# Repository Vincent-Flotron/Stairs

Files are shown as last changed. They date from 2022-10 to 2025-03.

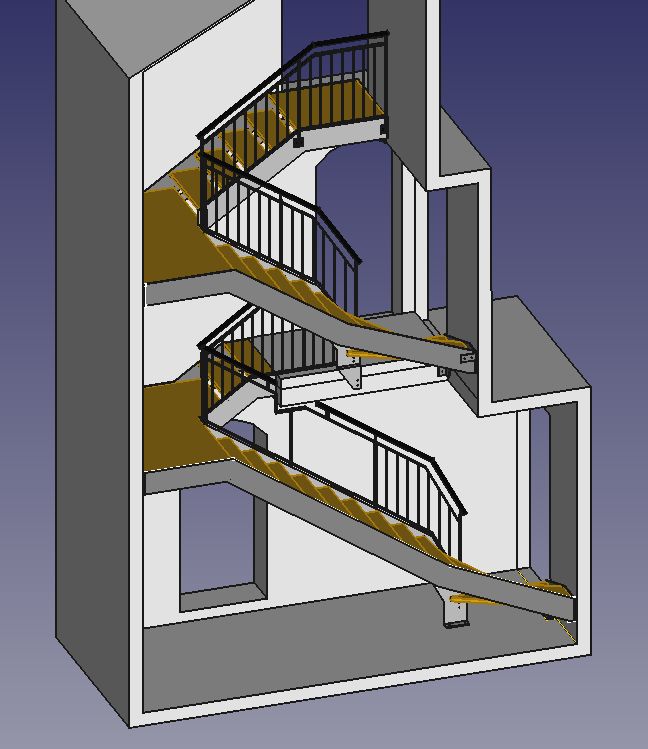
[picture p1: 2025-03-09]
overview.jpg

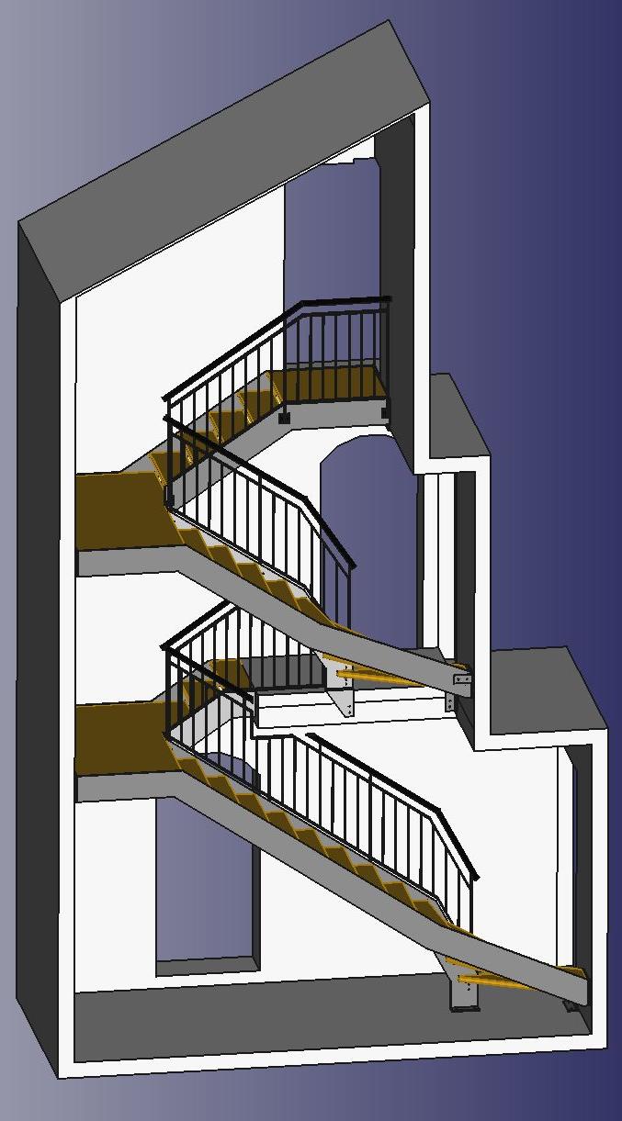
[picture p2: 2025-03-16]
VueGenerale.jpg

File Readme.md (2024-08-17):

# Escaliers fait avec FreeCAD

Voici des escaliers fait avec FreeCAD.
Ceux-ci utilisent une Spreadsheet afin de rendre certaines côtes paramétriques.

Un peu de code python a été ajouté dans le dossier Macro. Il sert à créer des body, les placer (selon la Spreadsheet) et les renommer afin de créer des marches.
Ce code est utilisé en copiant-collant son contenu dans la console FreeCAD.

Le feuille de calcul "Escalier.ods" est utilisée pour dimensionner les escaliers.

Lien sur la signification des icônes: <br/>
[https://wiki.freecad.org/Tree_view#Overlay_icons](https://wiki.freecad.org/Tree_view#Overlay_icons)

## Remerciements

Merci à [jp willm](https://www.youtube.com/channel/UCJwHW5GwrK1fq16cxUoBOUw/featured) pour ces vidéo sur FreeCAD qui m'ont beaucoup inspirées et mis à l'aise avec FreeCAD.

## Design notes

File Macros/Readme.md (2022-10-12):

# Macro

Le fichier **CreateSteps.py** n'est pas encore utilisé comme macro. Pour l'instant son contenu est copié dans la console **Freecad**. Puis la fonction **createSteps** est appelée comme ci-dessous afin de créer les corps (body) des marche et de les placer en "Z" en fonction de la Spreadsheet.

```python
createSteps(firstStep=1, nbSteps=2, firstBody=17, projectName='Maison', spreadsheet='Spreadsheet', stepPrefix='N')
```

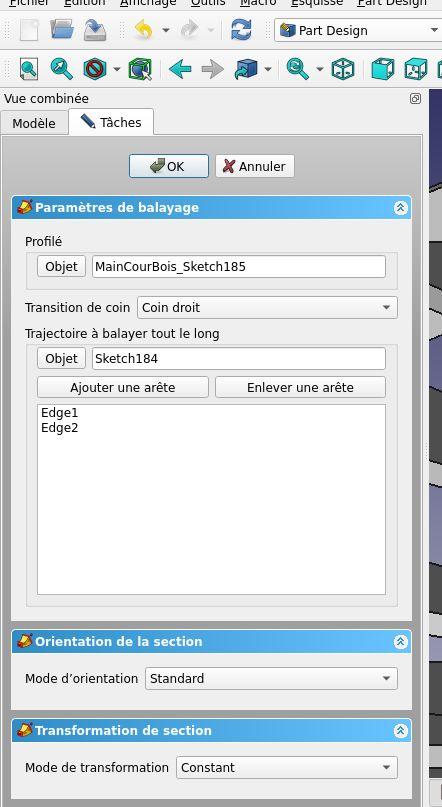
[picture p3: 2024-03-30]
mainCourante.jpg

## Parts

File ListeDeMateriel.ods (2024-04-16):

Liste de matériel :
Description | Matériau et dimensions [mm] | Quantité en barres de [6m] | Limons | fix marches | fix lim | fix barriere | barreaux
Barrières | Acier plat 10x40 | 15 | 1 | 8.4 | 0.5 | 0.195 | 22.0916666666667
Fix marches | Acier plat 8x50 | 12 | 6 | 3 |  |  | 44.1833333333333
Limons | Acier plat 15x250 | 8 | 2
Fix. Limonx | Acier plat 80x12 | 1 | 3
Fix. Barrières | Acier plat 90x10 | 1 | 2
Fix. Main courante | Acier plat 14x4 (si pas 14x4 alors 15x4) | 1 | 6
Barreaux | Acier rond Diam10 | 15
Description | Matériau et dimensions [mm] | Quantité [pce]
Vis Fix. Limons | Vis acier zingué 6 pans extérieur M16x50 | 35 | 2
 | Ecrous acier zingué 6 pans M16 | 35 | 6
 | Rondelles acier zingué ressort M16 | 35 | 2
 | Rondelles acier zingué plates M16 | 70 | 4
Vis fix barrières | Vis acier zingué 6 pans extérieur M10x35 | 25 | 2
 | Rondelles acier zingué ressort M10 | 25 | 4
 | Rondelles acier zingué plates M10 | 25 | 5
 |  | Date : 16.04.2024
 |  |  | 45 |  |  |  | 66.275

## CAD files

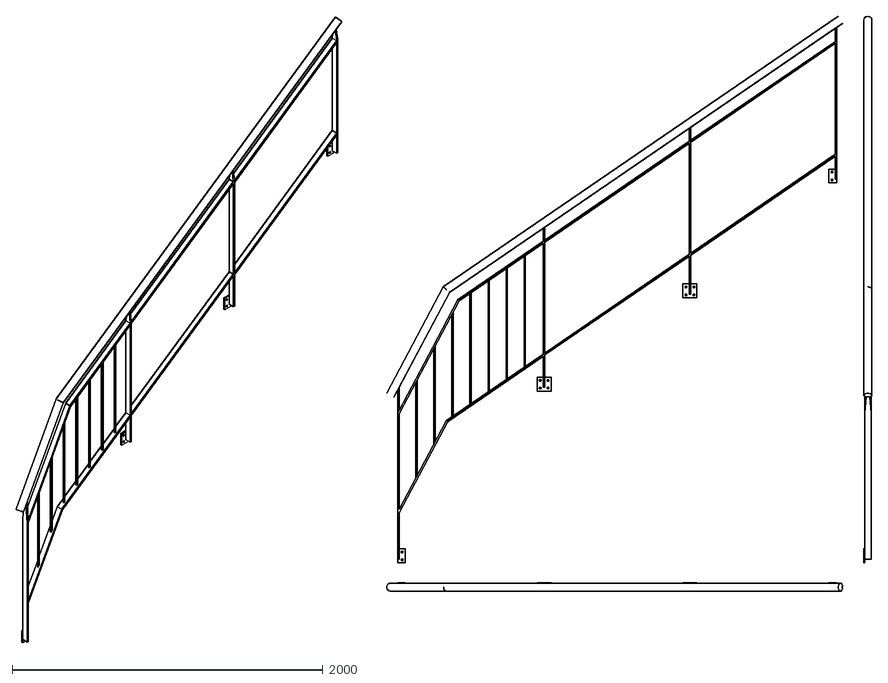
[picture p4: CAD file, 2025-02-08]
dxf/BarriereRez1ereVoleeBasGauche.dxf
5506.1 x 4028.6

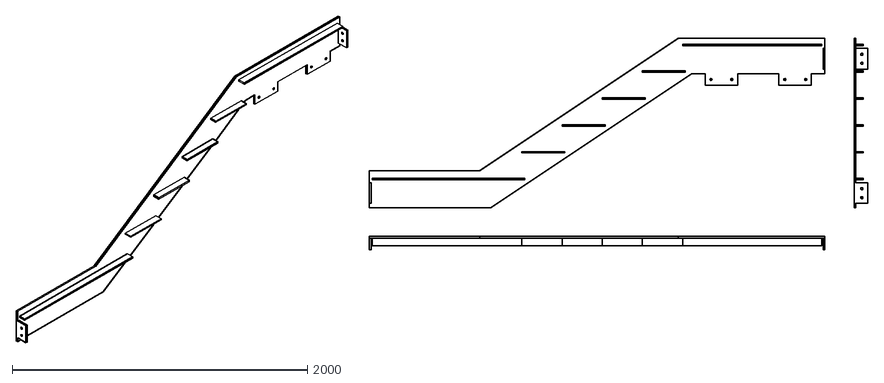
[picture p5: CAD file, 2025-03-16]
dxf/Epaiss12mm/Limon1er2emeVoleeGauche_V2.dxf
5764.3 x 2210.1

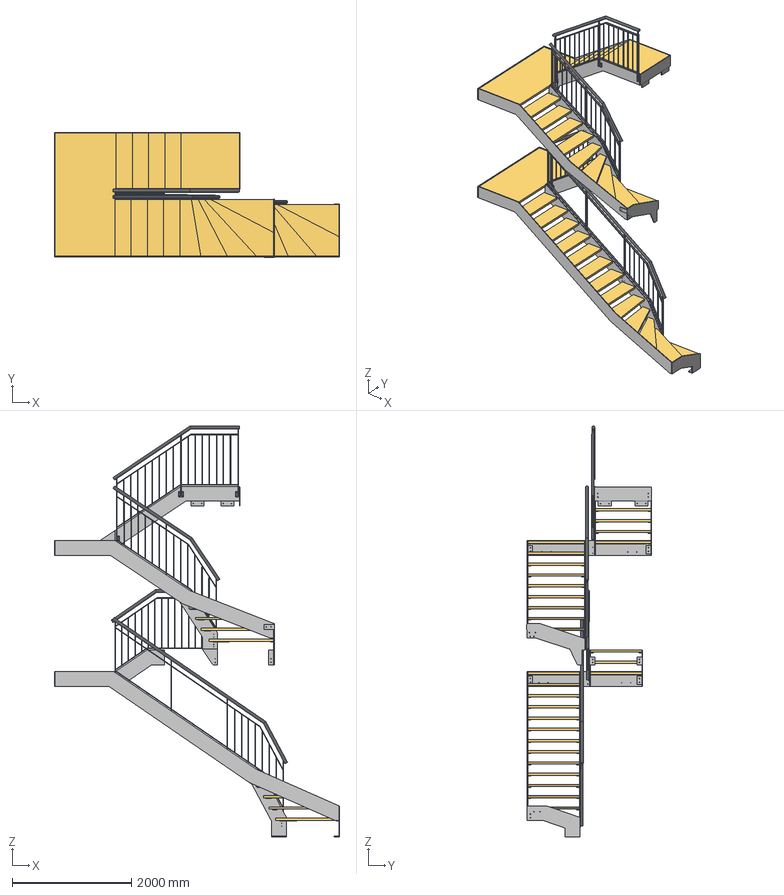
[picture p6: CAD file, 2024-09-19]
Maison2.FCStd
4779.0 x 2098.0 x 6882.0 mm
M1_Body003
M2_Body004
M3_Body005
M4_Body006
M5_Body007
M6_Body008
M7_Body009
M8_Body010
M9_Body011
M10_Body012
M11_Body013
M12_Body014
M13_Body015
M14_Body016
N1_Body017
N2_Body018
LimonRez1ereVoleeBasGauche_Body019
LimonRez1ereVoleeGauche_Body020
LimonRez2emeVoleeGauche_Body023
LimonRezPalier_Body024
NN1_Body025
NN2_Body026
NN3_Body027
NN4_Body028
NN5_Body029
NN6_Body030
NN7_Body031
NN8_Body032
NN9_Body033
NN10_Body034
NN11_Body035
NN12_Body036
NN13_Body037
NN14_Body038
NN15_Body039
Limon1er1ereVoleeBasGauche_Body040
Limon1er1ereVoleeGauche_Body041
Limon1er2emeVoleeGauche_Body043
Limon1erPalier_Body045
Limon1er2emePalier_Body046
BarriereRez1ereVoleeBasGauche_Corps
BarriereRez2emeVolee_Corps
Barriere1er1ereVolee_Corps
Barriere1er2emeVolee_Corps
LimonRez1ereVoleeDroite_Body021_Cut
LimonRez2emeVoleeDroite_Body022_Cut001
Limon1er1ereVoleeDroite_Body042_Cut003
Limon1er2emeVoleeDroite_Body044_Cut004

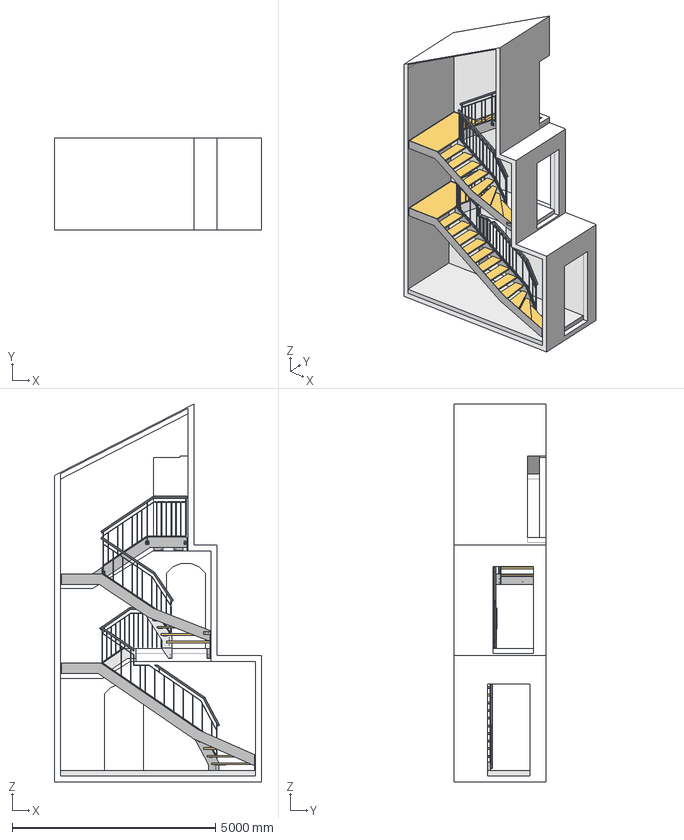
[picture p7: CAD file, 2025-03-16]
step_V2/Escaliers_V2.step
5103.0 x 2270.0 x 9300.2 mm
Murs_Body
M1_Body003
M2_Body004
M3_Body005
M4_Body006
M5_Body007
M6_Body008
M7_Body009
M8_Body010
M9_Body011
M10_Body012
M11_Body013
M12_Body014
M13_Body015
M14_Body016
N1_Body017
N2_Body018
LimonRez1ereVoleeBasGauche_Body019
LimonRez1ereVoleeGauche_Body020
LimonRez2emeVoleeGauche_Body023
LimonRezPalier_Body024
NN1_Body025
NN2_Body026
NN3_Body027
NN4_Body028
NN5_Body029
NN6_Body030
NN7_Body031
NN8_Body032
NN9_Body033
NN10_Body034
NN11_Body035
NN12_Body036
NN13_Body037
NN14_Body038
NN15_Body039
Limon1er1ereVoleeBasGauche_Body040
Limon1er1ereVoleeGauche_Body041
Limon1er2emeVoleeGauche_Body043
Limon1erPalier_Body045
Limon1er2emePalier_Body046
Chape_rez_Body
BarriereRez2emeVolee_Corps
Barriere1er1ereVolee_Corps
Barriere1er2emeVolee_Corps
LimonRez1ereVoleeDroite_Body021_Cut
LimonRez2emeVoleeDroite_Body022_Cut001
Limon1er1ereVoleeDroite_Body042_Cut003
Limon1er2emeVoleeDroite_Body044_Cut004

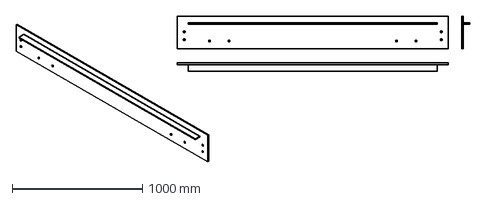
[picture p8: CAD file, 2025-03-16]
dxf/Epaiss12mm/Limon1erPalier_V2.dxf
3486.8 x 1118.4 mm

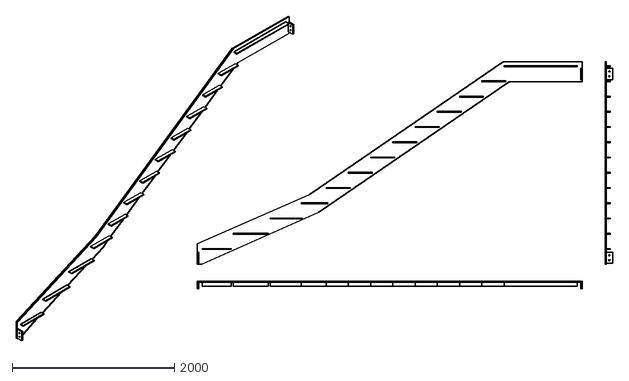
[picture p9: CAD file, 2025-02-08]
dxf/LimonRez1ereVoleeGauche.dxf
7362.8 x 4010.3

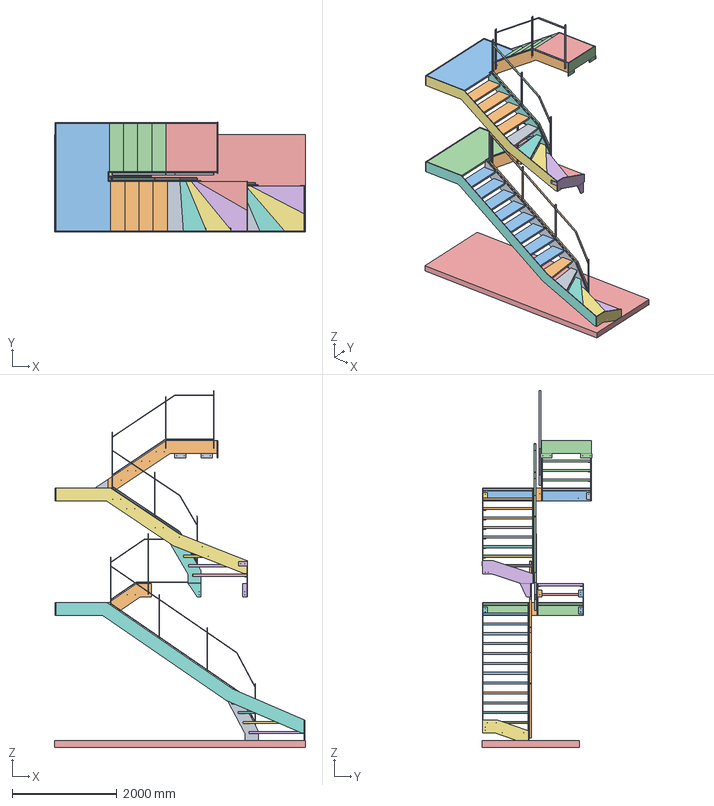
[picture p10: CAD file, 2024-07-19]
Maison2_v1.step
4803.0 x 2113.0 x 6830.0 mm
Barriere1er2emeVolee_Corps
BarriereRez1ereVoleeBasGauche_Corps
BarriereRez2emeVolee_Corps
Barriere1er1ereVolee_Corps
Chape_rez_Body
M1_Body003
M2_Body004
M3_Body005
M4_Body006
M5_Body007
M6_Body008
M7_Body009
M8_Body010
M9_Body011
M10_Body012
M11_Body013
M12_Body014
M13_Body015
M14_Body016
N1_Body017
N2_Body018
LimonRez1ereVoleeBasGauche_Body019
LimonRez1ereVoleeGauche_Body020
LimonRez1ereVoleeDroite_Body021
LimonRez2emeVoleeDroite_Body022
LimonRez2emeVoleeGauche_Body023
LimonRezPalier_Body024
NN1_Body025
NN2_Body026
NN3_Body027
NN4_Body028
NN5_Body029
NN6_Body030
NN7_Body031
NN8_Body032
NN9_Body033
NN10_Body034
NN11_Body035
NN12_Body036
NN13_Body037
NN14_Body038
NN15_Body039
Limon1er1ereVoleeBasGauche_Body040
Limon1er1ereVoleeGauche_Body041
Limon1er1ereVoleeDroite_Body042
Limon1er2emeVoleeGauche_Body043
Limon1er2emeVoleeDroite_Body044
Limon1erPalier_Body045
Limon1er2emePalier_Body046

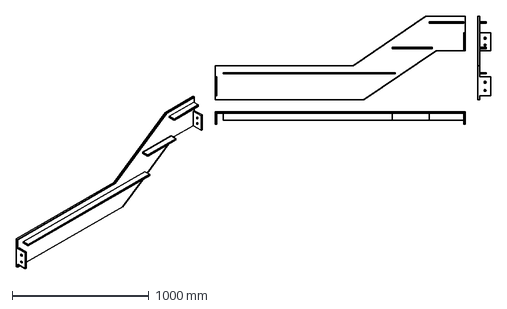
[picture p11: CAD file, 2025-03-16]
dxf/Epaiss12mm/LimonRez2emeVoleeGauche_V2.dxf
3470.2 x 1845.8 mm

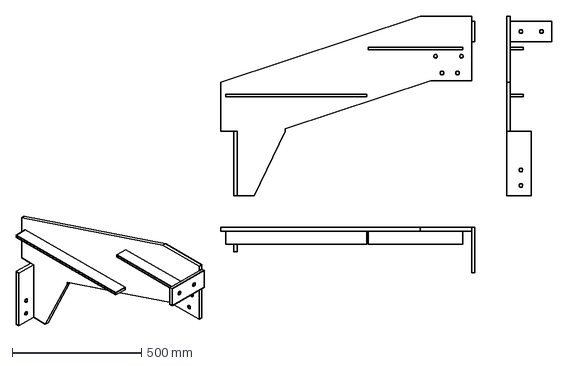
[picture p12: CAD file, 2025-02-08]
dxf/Limon1er1ereVoleeBasGauche.dxf
2071.2 x 1197.6 mm

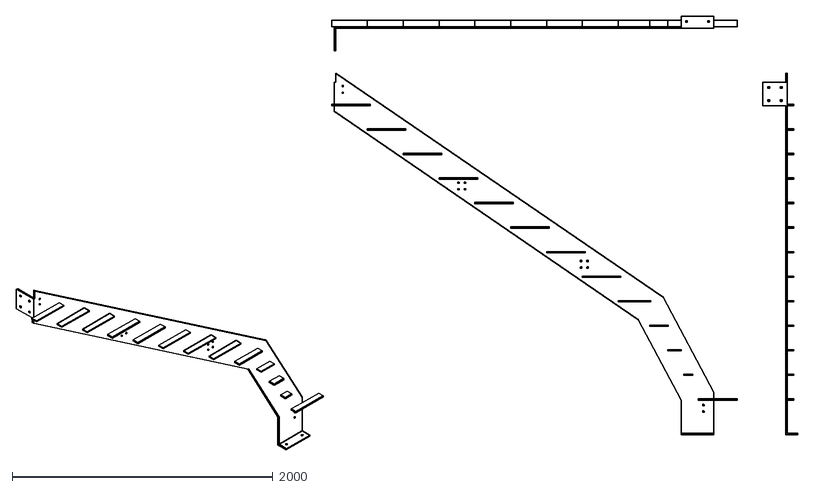
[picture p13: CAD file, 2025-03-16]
dxf/Epaiss12mm/LimonRez1ereVoleeDroite_V2.dxf
5987.0 x 3323.0

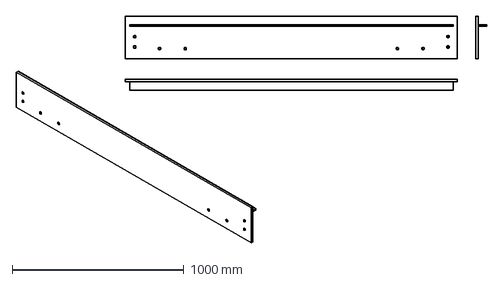
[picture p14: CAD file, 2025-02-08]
dxf/LimonRezPalier.dxf
2742.7 x 1322.5 mm

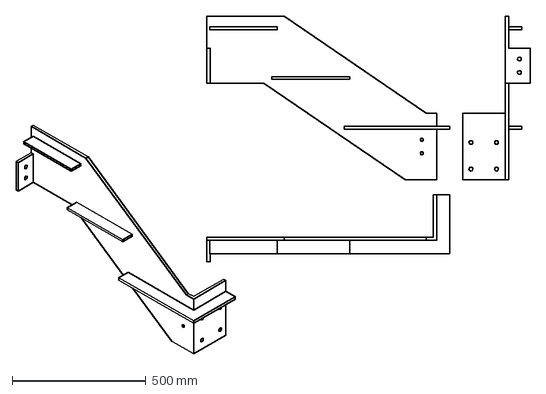
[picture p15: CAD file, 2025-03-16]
dxf/Epaiss12mm/LimonRez2emeVoleeDroite_V2.dxf
1920.2 x 1260.9 mm

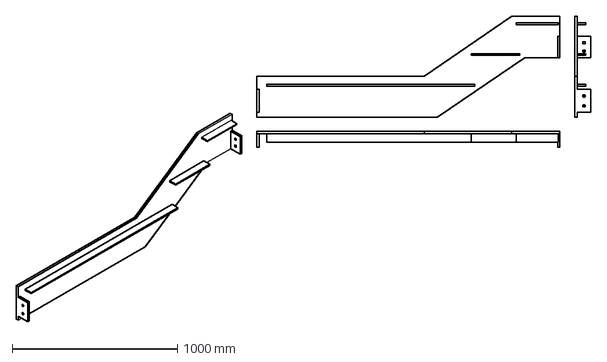
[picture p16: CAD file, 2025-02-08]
dxf/LimonRez2emeVoleeGauche.dxf
3472.8 x 1846.5 mm

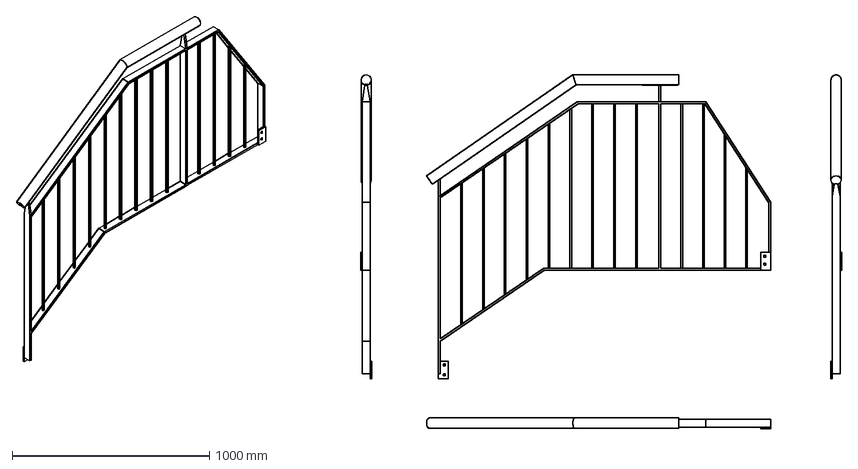
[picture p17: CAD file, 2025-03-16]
dxf/Epaiss12mm/BarriereRez2emeVolee_V2.dxf
4186.1 x 2091.0 mm

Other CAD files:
Maison.FCStd
dxf/Limon1er2emePalier.dxf
dxf/Epaiss12mm/LimonRez1ereVoleeBasGauche_V2.dxf
dxf/LimonRez2emeVoleeDroite.dxf
dxf/Barriere1er1ereVolee.dxf
dxf/Barriere1er2emeVolee.dxf
dxf/BarriereRez2emeVolee.dxf
dxf/Epaiss12mm/Barriere1er1ereVolee_V2.dxf
dxf/Epaiss12mm/Barriere1er2emeVolee_V2.dxf
dxf/Epaiss12mm/BarriereRez1ereVoleeBasGauche_V2.dxf
dxf/Epaiss12mm/Limon1er1ereVoleeBasGauche_V2.dxf
dxf/Epaiss12mm/Limon1er1ereVoleeDroite_V2.dxf
dxf/Epaiss12mm/Limon1er1ereVoleeGauche_V2.dxf
dxf/Epaiss12mm/Limon1er2emePalier_V2.dxf
dxf/Epaiss12mm/Limon1er2emeVoleeDroite_V2.dxf
dxf/Epaiss12mm/LimonRez1ereVoleeGauche_V2.dxf
dxf/Epaiss12mm/LimonRezPalier_V2.dxf
dxf/Epaiss12mm/Vue_Générale.dxf
dxf/Limon1er1ereVoleeDroite.dxf
dxf/Limon1er1ereVoleeGauche.dxf
dxf/Limon1er2emeVoleeGauche.dxf
dxf/Limon1erPalier.dxf
dxf/LimonRez1ereVoleeBasGauche.dxf
dxf/LimonRez1ereVoleeDroite.dxf

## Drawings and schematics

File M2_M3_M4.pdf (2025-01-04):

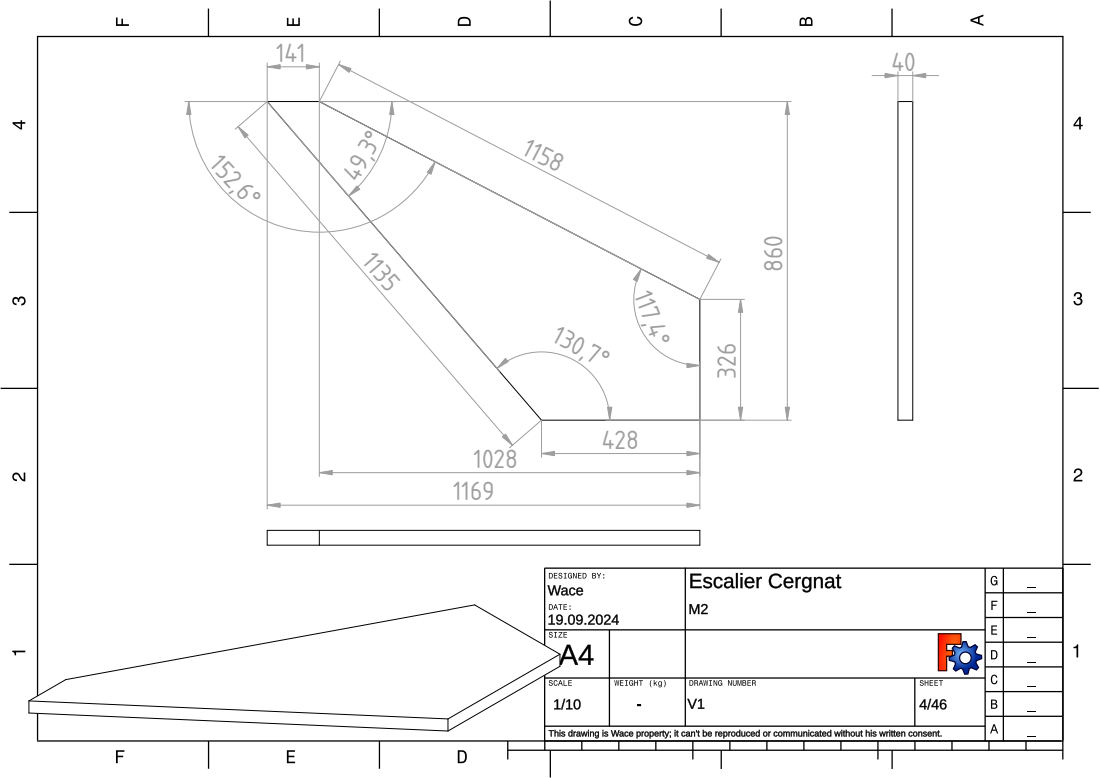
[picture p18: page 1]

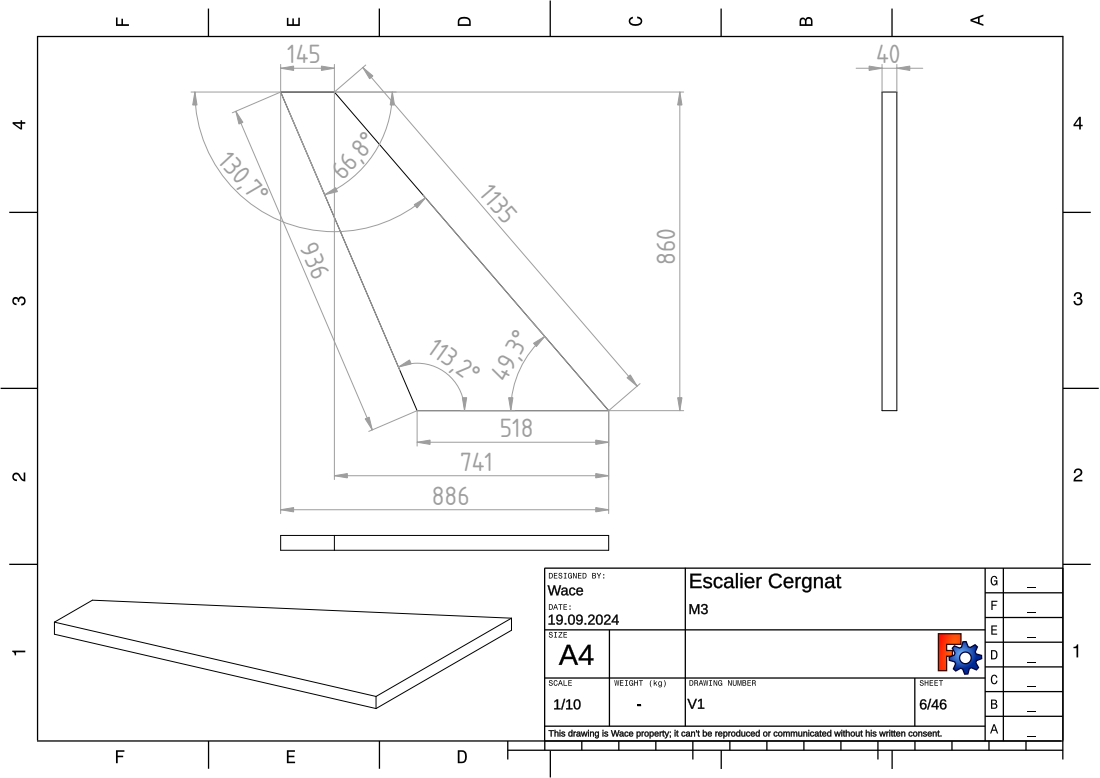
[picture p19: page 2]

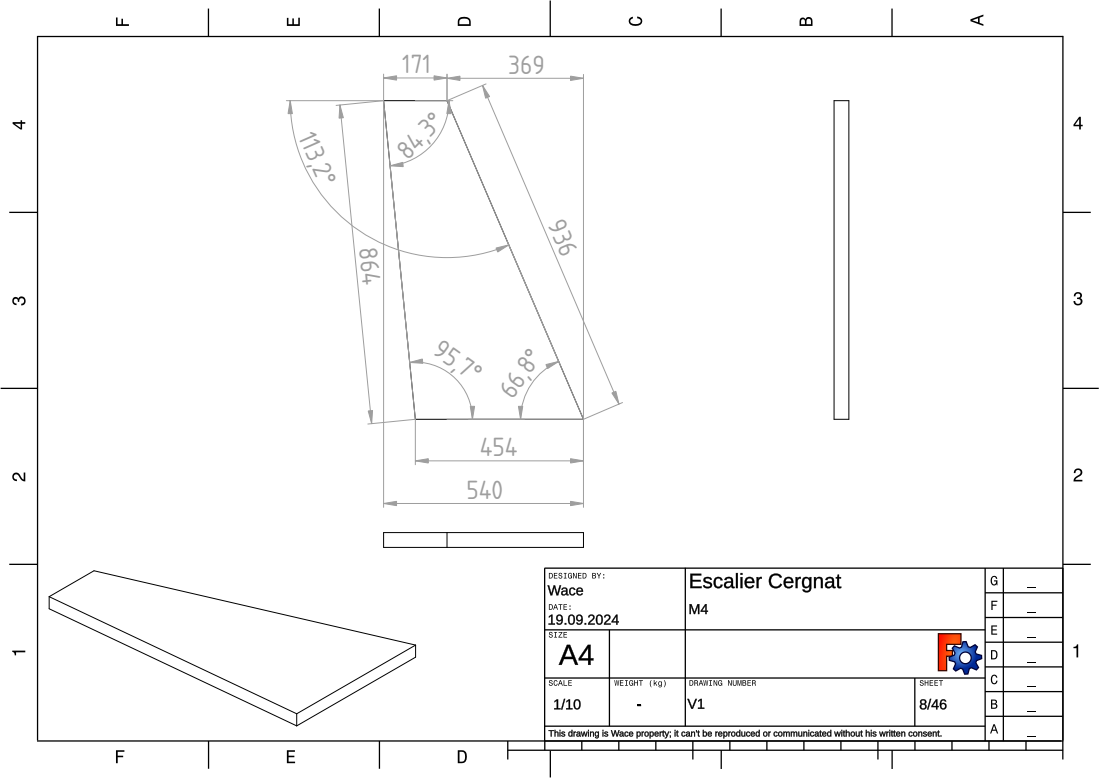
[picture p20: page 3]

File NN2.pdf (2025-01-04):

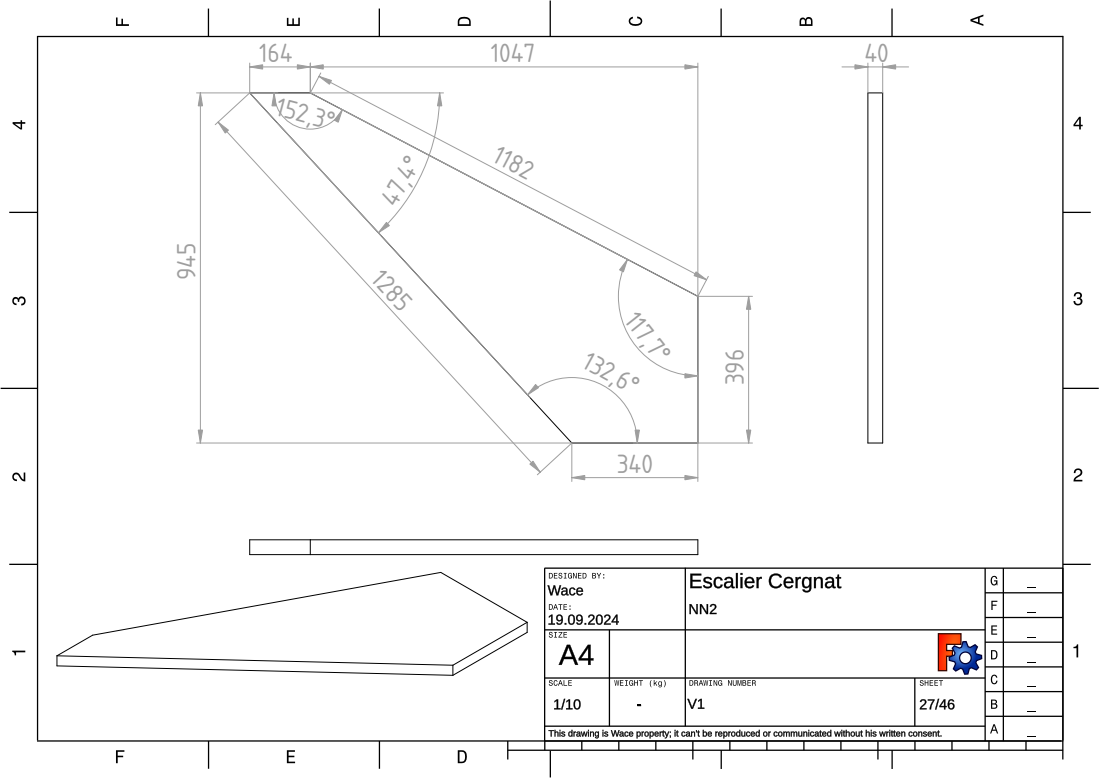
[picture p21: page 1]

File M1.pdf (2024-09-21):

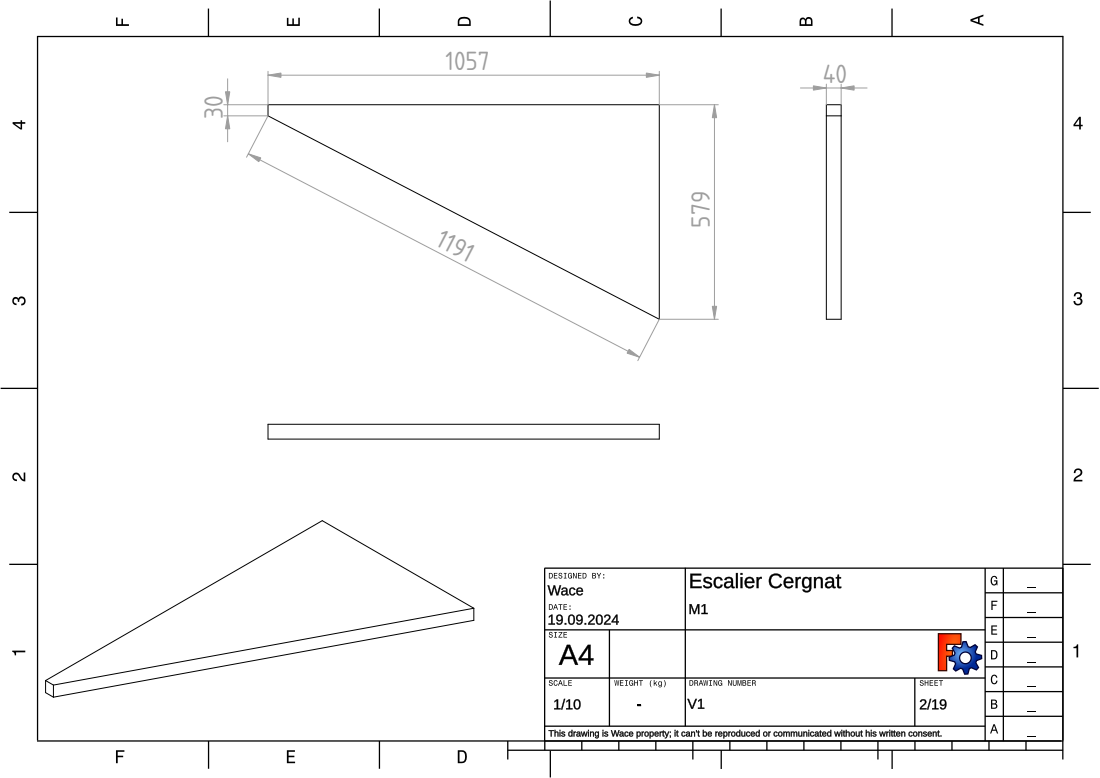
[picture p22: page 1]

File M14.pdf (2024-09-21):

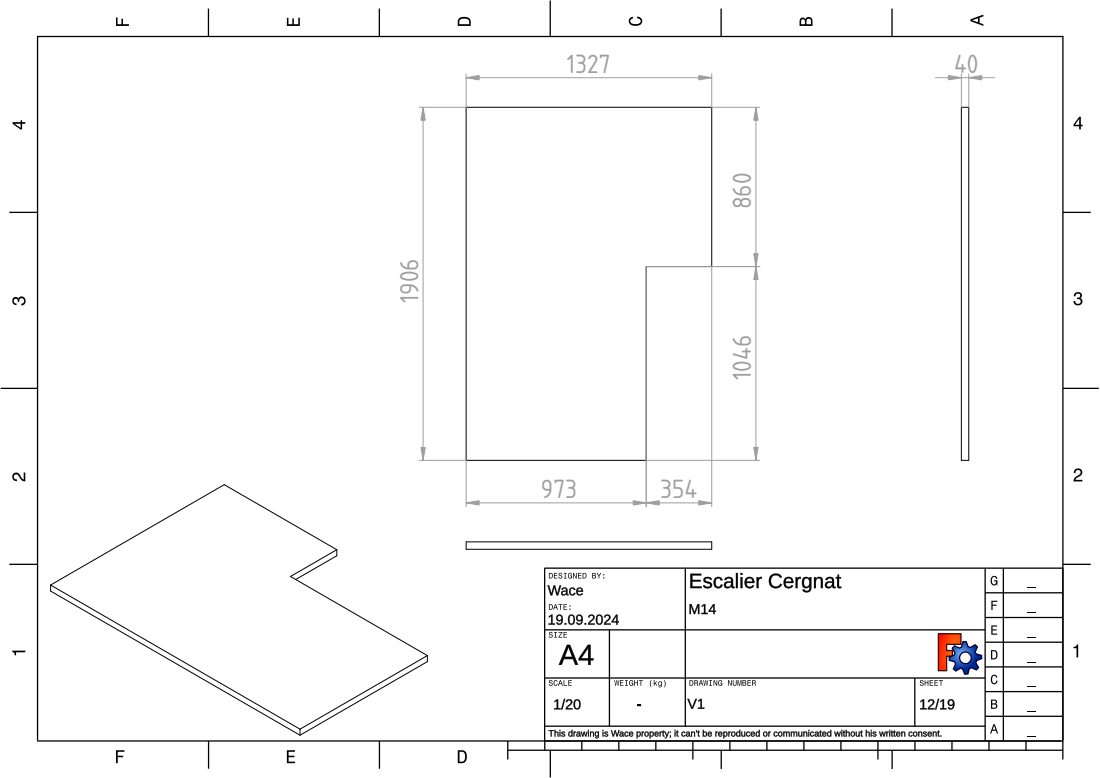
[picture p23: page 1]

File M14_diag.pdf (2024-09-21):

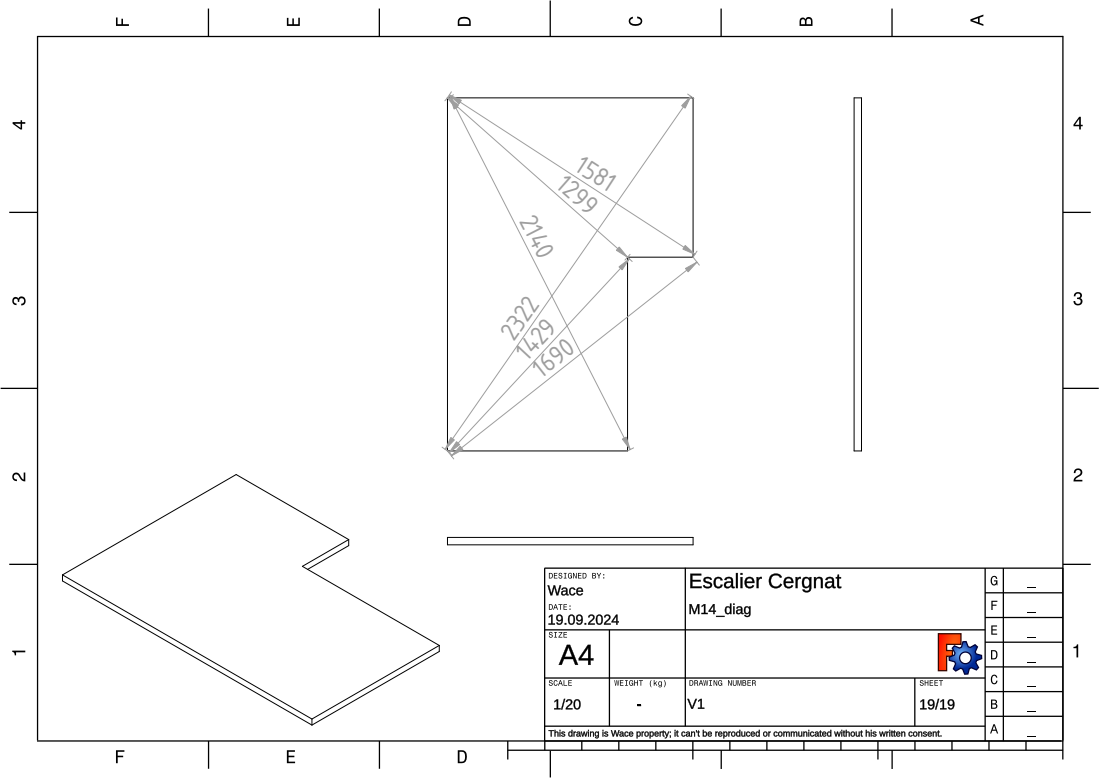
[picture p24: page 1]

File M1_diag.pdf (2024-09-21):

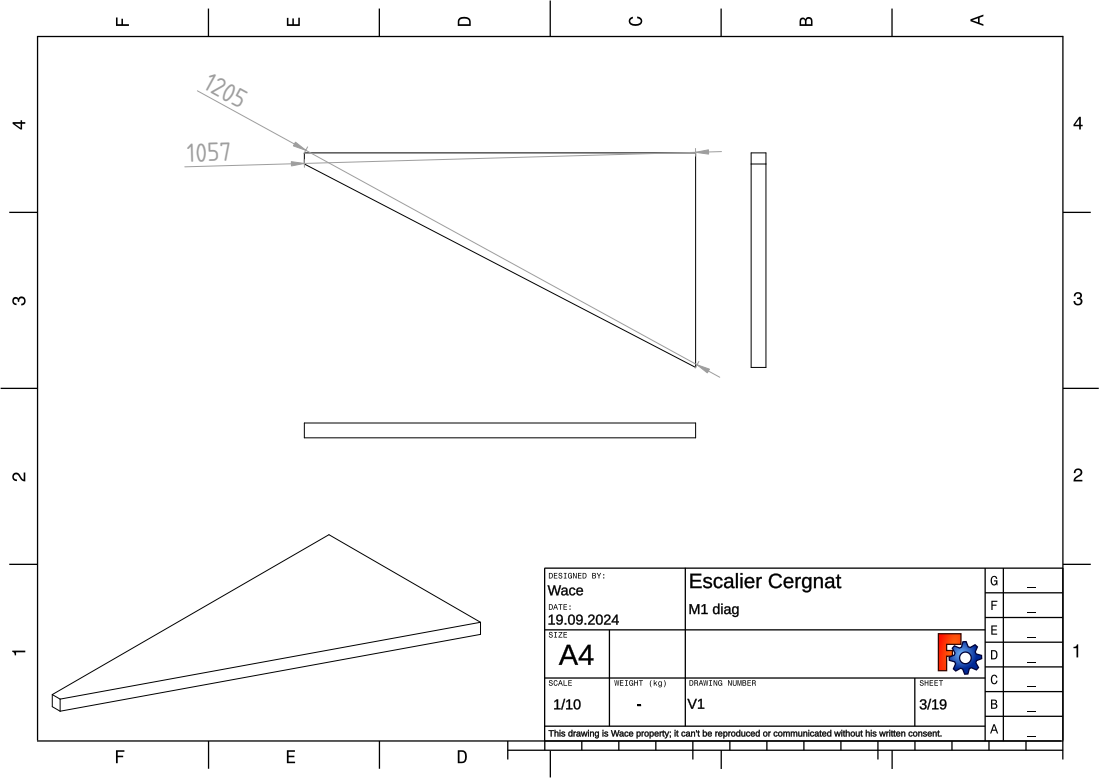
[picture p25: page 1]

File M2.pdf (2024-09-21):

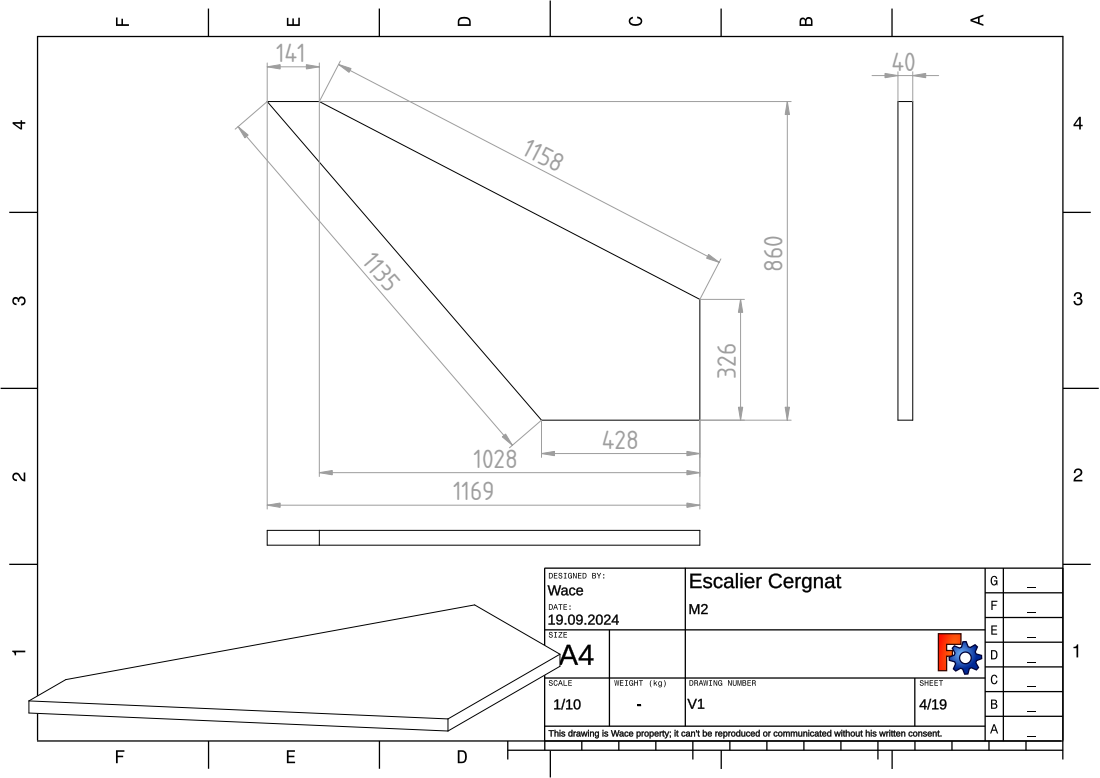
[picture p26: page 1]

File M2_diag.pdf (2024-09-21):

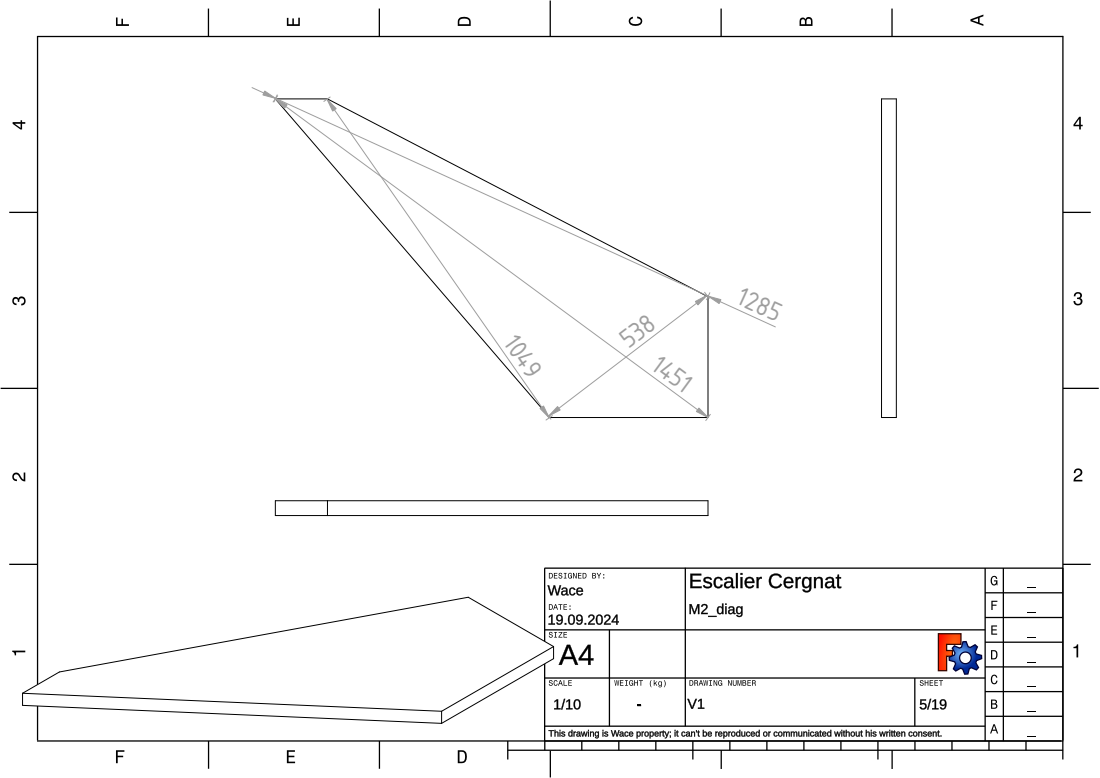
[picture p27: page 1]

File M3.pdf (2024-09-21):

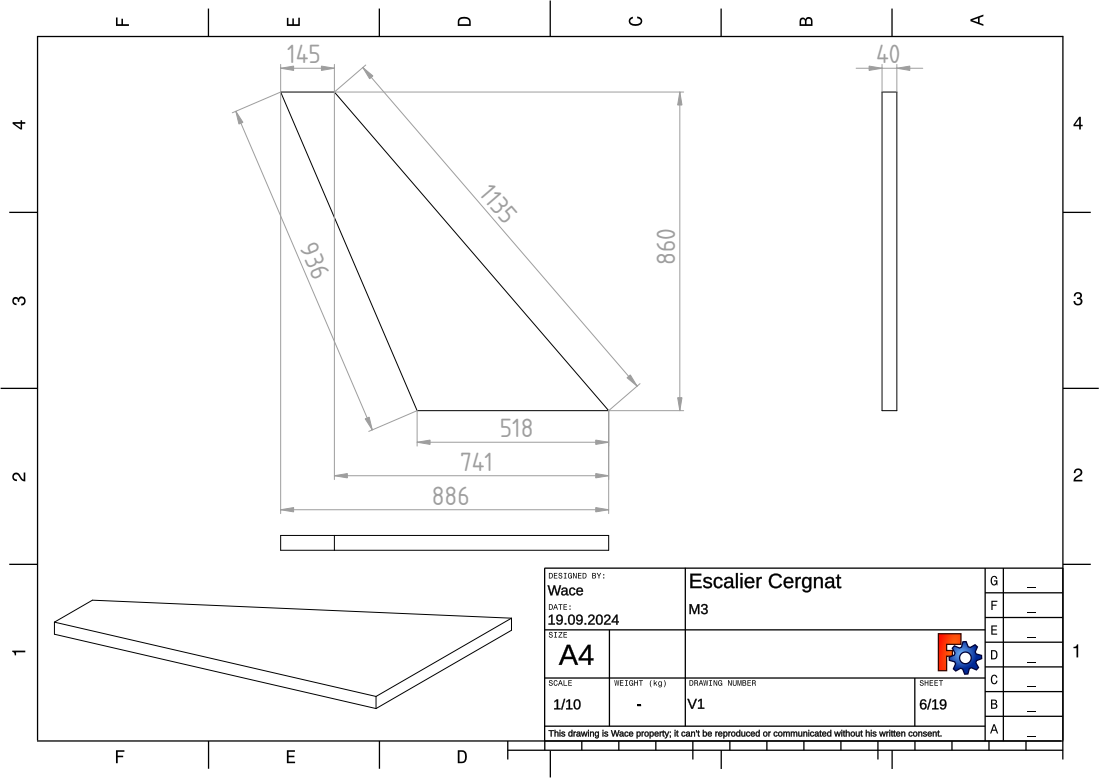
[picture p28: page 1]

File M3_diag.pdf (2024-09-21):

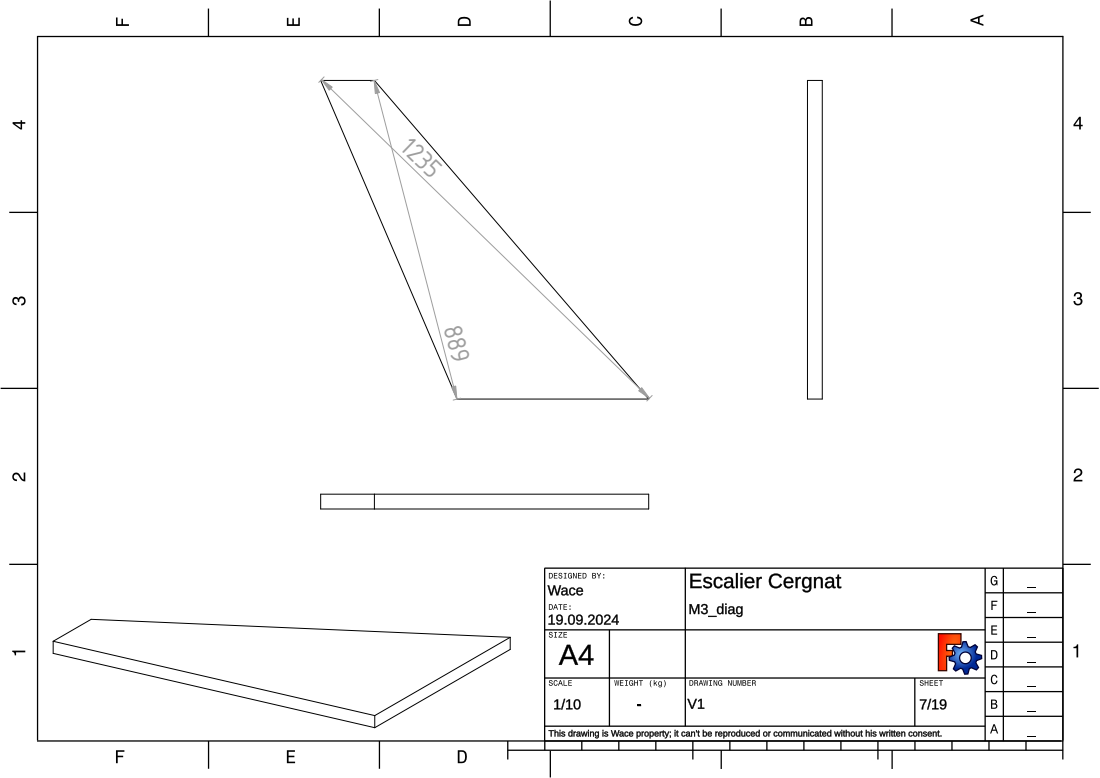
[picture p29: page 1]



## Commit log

2022-10-02 Murs done
    [Maison.FCStd, Maison20221002_0920.FCStd]
2022-10-02 PatronSol done.
    [Maison.FCStd]
2022-10-02 Just test
    [Maison.FCStd]
2022-10-02 Fueille de calcul ajoutée
    [Escalier.ods]
2022-10-02 Plans marches rez prêtes.
    [Escalier.ods, Maison.FCStd]
2022-10-08 Hauteur de la première volée rez Ok.
    [Escalier.ods, Maison.FCStd]
2022-10-08 Hauteur de la 2ème volée Ok
    [Escalier.ods, Maison.FCStd]
2022-10-08 Esquisse des marches du rez Ok
    [Escalier.ods, Maison.FCStd]
2022-10-08 Commencé l'esquisses de la 1ère volée du 1er étage.
    [Escalier.ods, Maison.FCStd]
2022-10-09 Spreadsheet ajoutée pour les mesures
    [Maison.FCStd]
2022-10-09 spreadsheet: répartition des marches Ok
    [Maison.FCStd]
2022-10-09 bodys marches rez, 1ère volée générées par script. (CreateSteps.py)
    [Maison.FCStd]
2022-10-09 Marches rez faites
    [Maison.FCStd]
2022-10-09 Trous marches rez ok.
    [Maison.FCStd]
2022-10-09 2 premiers limons gauches du rez commencés.
    [Maison.FCStd]
2022-10-12 Limons intérieurs rez ajoutés
    [Maison.FCStd]
2022-10-13 Limon rez 2ème volée droite Ok
    [Maison.FCStd]
2022-10-13 Commencé limon palier rez
    [Maison.FCStd]
2022-10-13 Limon palier Ok
    [Maison.FCStd]
2022-10-13 Marches 1er faites. Trous à faire
    [Maison.FCStd]
2022-10-13 Trous marches 1er Ok.
    [Maison.FCStd]
2022-10-16 1er: 2 premiers limons ajoutés
    [Maison.FCStd]
2022-10-18 1er: limon droite 1ère volée commencé
    [Maison.FCStd]
2022-10-18 Rez: fixation limons centraux Ok
    [Maison.FCStd]
2022-10-18 1er: limon droite 2ème volée Ok
    [Maison.FCStd]
2022-10-18 1er: limon palier Ok
    [Maison.FCStd]
2022-10-18 Silouhettes des limons terminée
    [Maison.FCStd]
2022-10-20 Fixations ajoutées
    [Maison.FCStd]
2022-10-21 Fixations pied escalier 1er et rez ajoutées
    [Maison.FCStd]
2022-10-24 fixations limons
    [Maison.FCStd]
2022-10-24 fixations terminées
    [Maison.FCStd]
2022-10-31 fixations ajoutées. Avant modif fix. marches
    [Maison.FCStd]
2023-09-22 Printed feet
    [Maison.FCStd]
2024-02-05 restarted 2024. Checked ok.
    [Maison.FCStd]
2024-02-08 ajouté fix 2ème volée haut
    [Maison.FCStd]
2024-02-08 ajouté 1 trou à fix 2ème volée bas
    [Maison.FCStd]
2024-03-02 started sup steps
    [Maison.FCStd]
2024-03-02 3ème limon sup marches
    [Maison.FCStd]
2024-03-02 réparé LimonRez2emeVoleeGauche_Body023
    [Maison.FCStd]
2024-03-02 escalier rez ok
    [Maison.FCStd]
2024-03-11 correction limons
    [Maison.FCStd]
2024-03-11 murs corrigé
    [Maison.FCStd]
2024-03-11 Limon1er2emeVoleeGauche_Body043 corrigé
    [Maison.FCStd]
2024-03-11 Limon1er2emeVoleeDroite_Body044 corrigé
    [Maison.FCStd]
2024-03-11 REPARE !
    [Maison.FCStd]
2024-03-11 premiere barriere
    [Maison.FCStd]
2024-03-11 premiere barriere suite
    [Maison.FCStd]
2024-03-30 1ere barriere en cours
    [Maison.FCStd]
2024-03-30 1ere barriere main cour
    [Maison.FCStd]
2024-03-30 1ere barriere barreaux
    [Maison.FCStd]
2024-03-30 avant rétrécissement marches
    [Maison.FCStd]
2024-03-30 pendant retrecissement marches
    [Maison.FCStd]
2024-04-05 ready to order
    [ListeDeMateriel.ods, Maison.FCStd]
2024-04-08 support marches 2eme volee 1
    [Maison.FCStd]
2024-04-08 2eme volée 2
    [Maison.FCStd]
2024-04-16 liste de matériel 16.04.2024
    [ListeDeMateriel.ods, Maison.FCStd]
2024-04-16 corrigé barrière rez 1ère volée
    [Maison.FCStd]
2024-05-24 barrière 1ère volée allongée et corr. fix limons
    [Maison.FCStd]
2024-05-24 sur main courante rez 2ème vol. Et corr. inv. limon bas gauche
    [Maison.FCStd]
2024-06-10 barrieres a distance et placees
    [Escalier.ods, Maison.FCStd]
2024-06-22 barrières, fix limons et support marche
    [Maison.FCStd, Maison2.FCStd]
2024-06-30 corrigé trou chape rez pour pied LimonRez1ereVoleeDroite_Body021
    [Maison2.FCStd]
2024-07-19 before transf
    [Maison2.FCStd, Maison2_v1.step]
2024-07-19 haut marches volee1 corr. Plaq. fix lim volee2 corr.
    [Escalier.ods, ListeDeMateriel.ods, Maison.FCStd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]
2024-07-19 augm. larg 1er, 1ere volee.
    [Maison2.FCStd]
2024-07-20 supports pour marches ajouté
    [Maison2.FCStd]
2024-07-20 support faits
    [Maison2.FCStd]
2024-07-20 revue supports en cours
    [Maison2.FCStd]
2024-07-20 support marche 1er 1ere volee
    [Maison2.FCStd]
2024-07-20 sup quart tournat 1er ok
    [Maison2.FCStd]
2024-07-20 sup quarts ok
    [Maison2.FCStd]
2024-07-20 barrières
    [Maison2.FCStd]
2024-08-13 just a commit
    [Maison2.FCStd]
2024-08-17 plaquettes main-courante faite
    [Maison2.FCStd]
2024-08-17 fix et main cour faites. Fix à checker.
    [Maison2.FCStd]
2024-08-17 fix barr ok. Limon haut ok.
    [Maison2.FCStd]
2024-08-17 trous limons bouchés
    [Maison2.FCStd]
2024-08-17 commencé barreaux
    [Maison2.FCStd]
2024-08-21 barreaux finis
    [Maison2.FCStd]
2024-08-21 trous fix bar. en cours
    [Maison2.FCStd]
2024-08-21 trous fix bar. termine
    [Maison2.FCStd]
2024-08-31 barrière faites
    [Maison2.FCStd]
2024-09-07 before transfert to Lu
    [Maison2.FCStd]
2024-09-19 Trous marches bouchés
    [Maison2.FCStd]
2024-09-19 making plans
    [Maison2.FCStd]
2025-01-04 re-started dxf
    [LimonRez1ereVoleeBasGauche.dxf, LimonRez1ereVoleeDroite_3-3.dxf]
2025-01-04 decoupelaser added (dxf)
    [#LimonRez1ereVoleeBasGauche.dxf, #M1.dxf, LimonRez1ereVoleeBasGauche.dxf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]
2025-02-08 dxf terminés
    [#LimonRez1ereVoleeBasGauche.dxf, #M1.dxf, Barriere1er1ereVolee.dxf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]
2025-03-16 Version finale V2
    [Barriere1er1ereVolee_V2.dxf, Barriere1er2emeVolee_V2.dxf, BarriereRez1ereVoleeBasGauche_V2.dxf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]
